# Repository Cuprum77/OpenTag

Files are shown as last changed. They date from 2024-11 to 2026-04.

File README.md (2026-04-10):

# OpenTag

OpenTag is a project for building custom Bluetooth location finding beacons based on existing Apple and Google location finding networks. This repository contains the hardware and firmware for and STM32WB5x/35xx based "Polyglot" tag that can use both Google and Apple finding networks simultaneously. The repository also contains 3D printable enclosures for the tag as well as a docker based web interface for aggregating the results from the different location fetching backends.

## Backends
We did not invent or even do anything novel in terms of reverse engineering the Apple and Google finding networks. Thus, we rely on third party implementations of both to do the heavy lifting needed to make this project feasible, in particular:
- [Macless-Haystack](https://github.com/dchristl/macless-haystack) Used for fetching location data from the Apple finding network.
- [GoogleFindMyTools](https://github.com/leonboe1/GoogleFindMyTools) Used as a base for the Google finding network backend. (Note: A fork with additional features such as key rotation, compound tags and more was created based on GoogleFindMyTools and is used in this project, the fork is available [here](https://github.com/diminDDL/OpenTagBridge)).

## Hardware
The hardware design (located in the [hardware](./hardware) directory) for the Polyglot tag is based on the STM32WB5x/35xx series of microcontrollers and is powered with a single CR2032 battery. When actively advertising payloads it consumes around 3mA, in deep sleep that number drops to 3uA. By default the tag wakes up every 10 seconds for a ~25ms long advertising window and with a single 230mAh CR2032 cell the tag is expected to last for about 2 years and 6 months. The parameters can be adjusted for different use cases and battery life tradeoffs. The following formula can be used to estimate battery lifetime:

$$
I_{\mathrm{avg}}=
I_{\mathrm{active}}\cdot\frac{t_{\mathrm{active}}}{T_{\mathrm{cycle}}}
+
I_{\mathrm{sleep}}\cdot\left(1-\frac{t_{\mathrm{active}}}{T_{\mathrm{cycle}}}\right)
$$

$$
\text{Battery Life (years)} =
\frac{C_{\mathrm{bat}}}{I_{\mathrm{avg}}\cdot 24 \cdot 365}
$$

or equivalently

$$
\text{Battery Life (years)} =
\frac{C_{\mathrm{bat}}}
{\left(
I_{\mathrm{active}}\cdot\frac{t_{\mathrm{active}}}{T_{\mathrm{cycle}}}
+
I_{\mathrm{sleep}}\cdot\left(1-\frac{t_{\mathrm{active}}}{T_{\mathrm{cycle}}}\right)
\right)\cdot 24 \cdot 365}
$$

Where by default the parameters are:

$$
I_{\mathrm{active}} = 3.0\ \text{mA}
$$

$$
I_{\mathrm{sleep}} = 0.003\ \text{mA}
$$

$$
t_{\mathrm{active}} = 24\ \text{ms}
$$

$$
T_{\mathrm{cycle}} = 10\ \text{s}
$$

$$
C_{\mathrm{bat}} = 230\ \text{mAh}
$$

There is also a large capacitor bank on the board, it is optional, however it contains enough energy for a few advertisement bursts which can prevent the tag from resetting in high vibration environments.

The tag uses an integrated single part matching network from ST and a PCB antenna offering quite consistent RF performance without the need for manual tuning. A 4 layer stackup is used for better RF performance, but it could be simplified to 2 layers and a thinner stackup if needed.

The board also includes 2 LEDs, 2 jumpers for debugging and programming and an SWD pad compatible with a Tag-Connect.

## Firmware
See the [software](./software) directory for the firmware source code, build and programming instructions.

## Mechanical
The [3d_models](./3d_models) directory contains the 3D models for the tag itself, and the [enclosures](./enclosures) directory contains 3D models for enclosures.

## Aggregation and Web Interface
*TODO*

# Disclaimer
> [!CAUTION]
> This project is provided for educational and research purposes only. The authors and contributors disclaim liability and do not condone illegal, unauthorized, or unethical use, including unauthorized tracking or invasions of privacy.
> 
> Use of this project is entirely at your own risk. Interacting with Google or Apple location networks in undocumented or unsupported ways may violate platform rules or terms of service and may result in account penalties, service restrictions, or other consequences. The authors and contributors disclaim liability for misuse of this repository and for any damages or consequences resulting from its use.

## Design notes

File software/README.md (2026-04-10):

# Software Overview

*TODO*

---

# Firmware Installation

The firmware is written in C/C++ using STM32CubeIDE. You don't need to compile the firmware if you are fine with the default settings:
- 1 key broadcast every 10 seconds
- 360 key re-use cycles (key changes once every hour)

You can modify these [here](STM32WB_BT_TAG/STM32_WPAN/App/app_ble.c#L177-L185).

---

### Wireless Stack Installation

1. **Download STM32CubeProgrammer**:  
   Go [here](https://www.st.com/en/development-tools/stm32cubeprog.html) to download the STM32CubeProgrammer.  

2. **Prepare Your Hardware**:  
   *Short the `BOOT0` jumper to the 3V3 rail (2nd jumper from the top on the right side if viewed with antenna up).* This may be optional depending on the state of the flash.

   Connect your board to a debugger (preferably an ST-LINK), and connect the debugger to your computer.
   BOOT0 (top right) and the pinout of the debug connector (bottom right) is shown below:
   
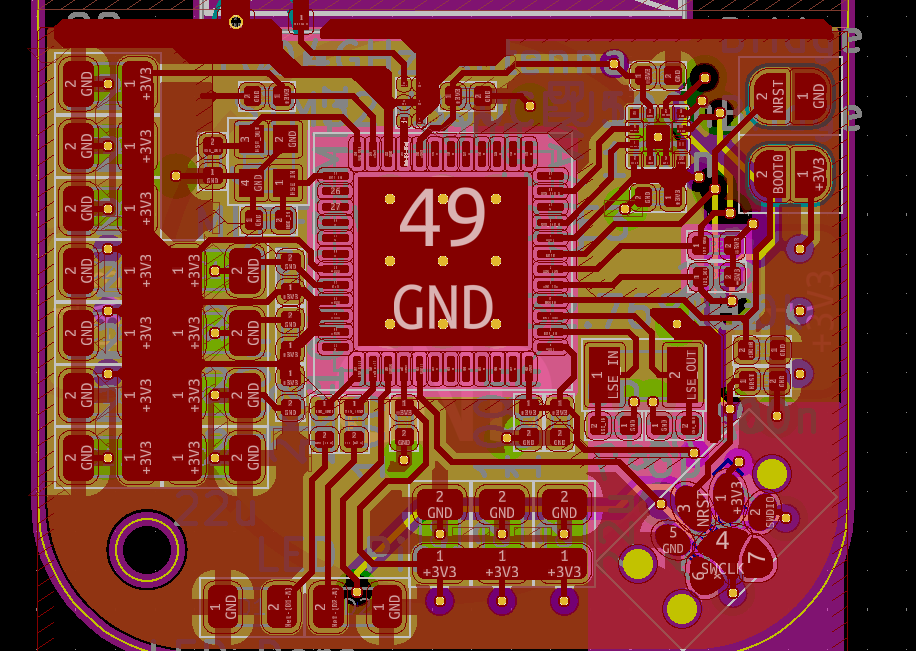
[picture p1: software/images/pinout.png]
Image of the board layout
   

   You only need 3V3, GND, SWDIO, and SWCLK from the debug connector. 

4. **Install the Wireless Stack and Firmware Update Service**:  
   Visit [STM32WB_Copro_Wireless_Binaries](https://github.com/STMicroelectronics/STM32CubeWB/tree/master/Projects/STM32WB_Copro_Wireless_Binaries) and download 3 files:
   - `stm32wb3x_FUS_fw.bin`
   - `stm32wb3x_BLE_Stack_full_fw.bin`
   - `Release_Notes.html`
   
   Open `Release_Notes.html` in your browser. Here you need to find a table called "FW Upgrade Services Binary", it should include an entry for `stm32wb3x_FUS_fw.bin` and the address of where that binary should be programmed to depending on flash size. Use [STM32CubeProgrammer](https://www.st.com/en/development-tools/stm32cubeprog.html) to find what flash size you have (shown in bottom right after you connect to the target).

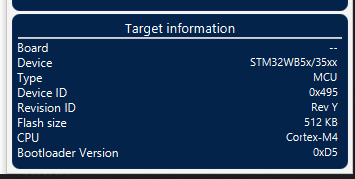
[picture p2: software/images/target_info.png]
Screenshot of STM32CubeProgrammer showing target info
   

   After connecting to the target, open the **"Firmware Upgrade Services"** tab in STM32CubeProgrammer, click **"Start FUS"** under the **"WB Commands"** section, and then **"Read FUS infos"**. This will show you the current FUS version on the MCU. Now select `stm32wb3x_FUS_fw.bin` in the file selector, enter the start address if STM32CubeProgrammer doesn't offer to auto detect the address. Hit **"Firmware Upgrade"** and wait for it to finish, once it's done once again click "Start FUS" and **"Read FUS infos"** and double check if the FUS version matches the one you downloaded.

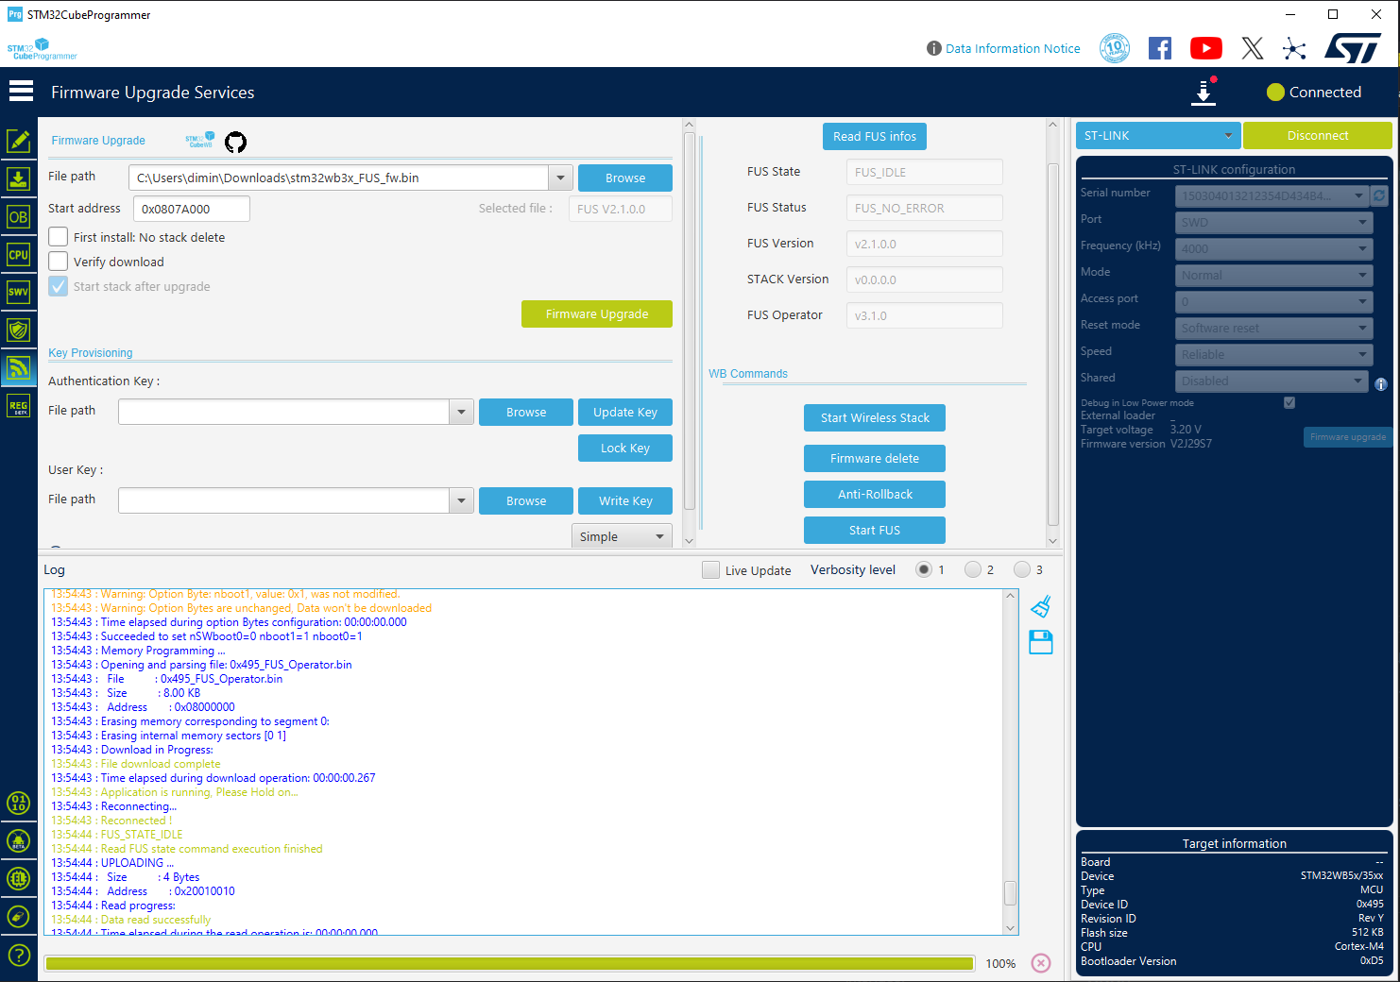
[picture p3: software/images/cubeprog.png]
Screenshot of STM32CubeProgrammer
   

   Now you need to program the BLE stack. Take the `stm32wb3x_BLE_Stack_full_fw.bin` file and find it in `Release_Notes.html` to find the address depending on the flash size. Now select `stm32wb3x_BLE_Stack_full_fw.bin` in the file selector, enter the start address if STM32CubeProgrammer doesn't offer to auto detect the address and hit **"Firmware Upgrade"**. After this is done you should be able to "Read FUS infos" and see a **"STACK Version"** that shows an actual version and is not full of zeroes.

   **⚠️Important⚠️**

   Make absolutely sure you start the wireless stack after you flash it, without pressing that button in STM32CubeProgrammer the BLE will not work at all! The button to do so can be found in the **"Firmware Upgrade Services"** menu under **"WB Commands"**. First disconnect the debugger and make sure to completely power cycle the MCU (short the capacitors for good measure). Next re-connect to the target, and simply click **"Start Wireless Stack"** and wait for confirmation. 

   *If at a later point the tag doesn't advertise anything on Bluetooth then try enabling the wireless stack again, it sometimes resets itself after programming firmware.*

   Follow these instructions if you have any issues:
   - [STM32WB BLE Hardware Setup](https://wiki.st.com/stm32mcu/wiki/Connectivity:STM32WB_BLE_Hardware_Setup)
   - [YouTube Tutorial](https://www.youtube.com/watch?v=-xYoI84zJew&t=568s)  

---

### Firmware Installation

Once the wireless stack is set up, proceed as follows:

1. Open the **"Erasing & Programming"** section in STM32CubeProgrammer.  
2. Select the binary file located [here](STM32WB_BT_TAG/Release/STM32WB_BT_TAG.hex).  
3. Ensure that the **"Skip flash erase before programming"** checkmark is **unchecked**.  
4. Click **Start Programming**.  

Now the MCU has firmware, but keys still need to be installed. Also, now SWD connections won't work if the tag is in deep sleep. So, if the device isn't responding to the debugger power cycle it and try connecting within the first 30 seconds while the LED is blinking.

---

### Key Installation

1. **Generate Keys**:  
   Use the [Macless-Haystack](https://github.com/dchristl/macless-haystack) project to generate Apple keys, specifically the [generate_keys.py](https://github.com/dchristl/macless-haystack/releases/latest/download/generate_keys.py) script, to produce a binary file containing the keys. Once the script produces the files, you need to find the smallest one (`_keyfile` postfix) without an extension and rename it to have a `.bin` at the end. Otherwise STM32CubeProgrammer will not accept it.
   *(Note: Generating multiple keys in the file is left as an exercise for the reader.)*

   Use [OpenTagBridge](https://github.com/diminDDL/OpenTagBridge) to log into Google and register a tracker to get the the Google keys. A `.bin` file will be generated.

2. **Program the Keys**:  
   - Open the **"Erasing & Programming"** section in STM32CubeProgrammer.  
   - Select the generated `.bin` file.  
   - Set the following options:
     - **Unchecked**: "Skip flash erase before programming" (should be blue).
     - **Start Address**: `0x08020000` for Google keys.
     - **Start Address**: `0x08030000` for Apple keys.  
   - Click **Start Programming**.
   - Repeat the above steps for both Apple and Google keys.

The keys are now programmed. Disconnect power and the programmer from the device, ⚠️**DISCHARGE THE CAPACITORS**⚠️, insert a battery, and the device should start broadcasting your keys.

---

## Verifying Tag Functionality

To verify the tag is working:
1. Use [STBLEToolbox](https://www.st.com/en/embedded-software/stbletoolbox.html) on your phone. Place your phone right next to the tag, and put it into scanning mode and wait for several minutes. (You can power cycle the tag to force it to spam some keys at the start).  
2. The tag will report itself as an Apple Device with the following advertisement payload:  
   - **Length**: 26  
   - **Type**: 0xFF  
   - **Value**: 0x...  
3. The app should identify it as an iBeacon.
4. The tag will also advertise itself as a Unknown device with a random MAC address and the following advertisement payload:  
   - **Length**: 25  
   - **Type**: 0x16  
   - **Value**: 0x...

If you see the above advertisements with a high power (-30 to -45dBm) when placed next to your phone then the tag is fully operational and transmitting BLE beacons.

--- 

## Getting Location Data

Please follow the instructions from [Macless-Haystack](https://github.com/dchristl/macless-haystack) on how to setup your apple account and server for receiving location data. In particular `Server setup` and `Frontend setup` should be read and followed thoroughly.

Also, follow the instructions in [OpenTagBridge](https://github.com/diminDDL/OpenTagBridge) on dealing with Google accounts and getting the Google keys.

## Aggregated Web Interface
*TODO*

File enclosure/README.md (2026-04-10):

# Enclosure

The enclosure is designed to snap fit straight from the printer, please print at 0.2mm layer height or below. PETG is recommended for better durability of the snap-fit joints.

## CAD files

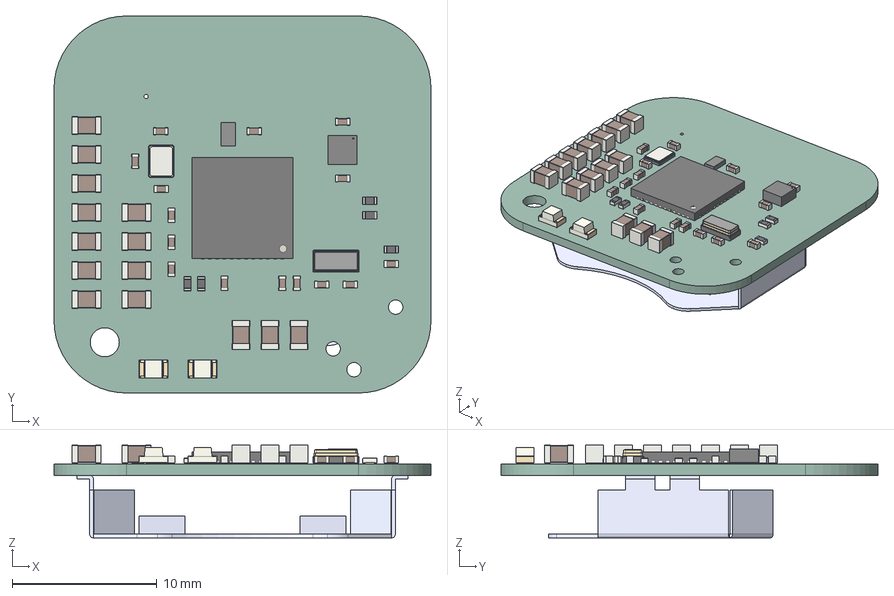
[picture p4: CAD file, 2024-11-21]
3d_models/OpenTag_noTracks.step
26.0 x 26.0 x 6.40 mm
C_0805_2012Metric x 14
C_0402_1005Metric x 15
Crystal_SMD_TXC_7M-4Pin_3.2x2.5mm_HandSoldering
LED_0805_2012Metric x 2
R_0402_1005Metric x 5
MLPF-WB55-01E3
QFN-48-1EP_7x7mm_Pitch0.5mm
Crystal_SMD_3215-2Pin_3.2x1.5mm
root
OpenTag_PCB

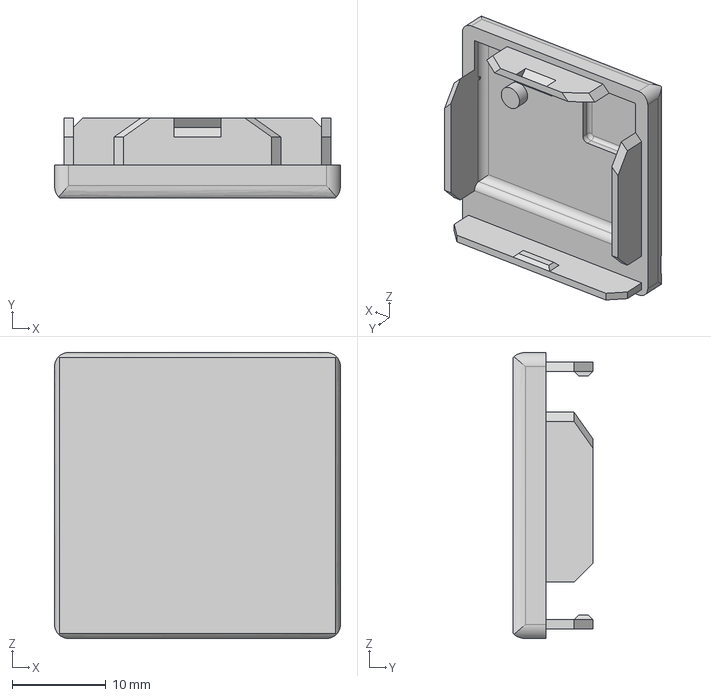
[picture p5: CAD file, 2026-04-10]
enclosure/OpenTagCase_top.step
30.5 x 8.50 x 30.5 mm

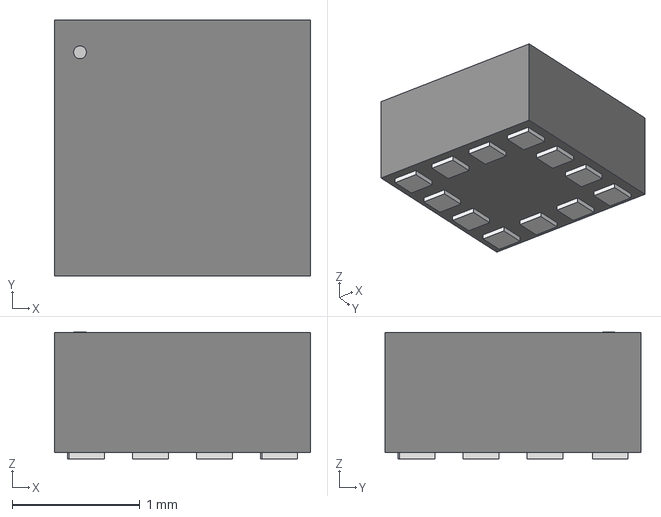
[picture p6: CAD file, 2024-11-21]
hardware/3D/QFN_BMA400_BOS.step
2.01 x 2.01 x 0.993 mm

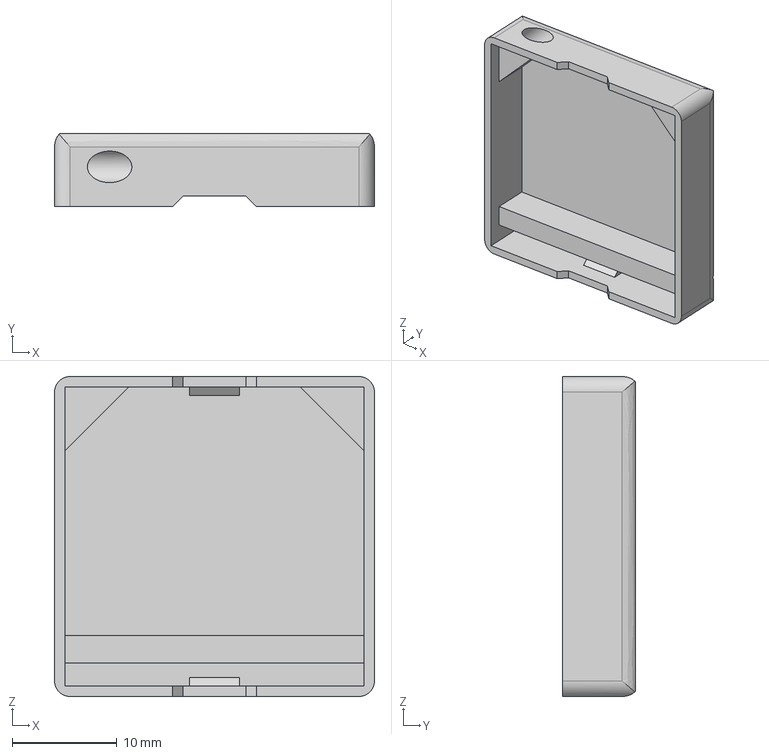
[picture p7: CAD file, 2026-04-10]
enclosure/OpenTagCase_bottom.step
30.5 x 7.00 x 30.5 mm

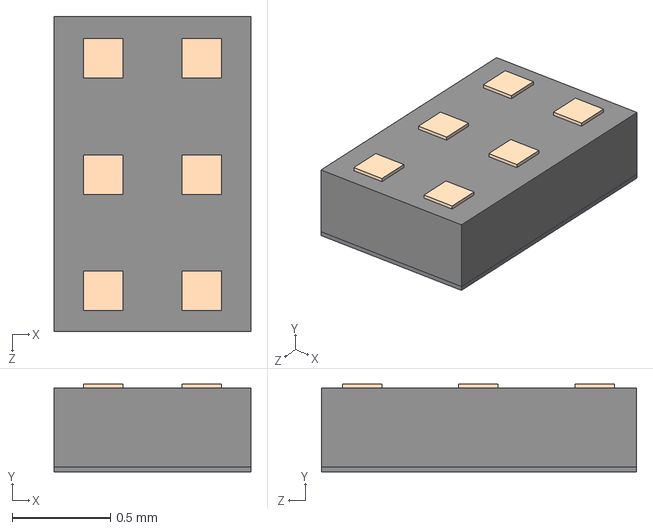
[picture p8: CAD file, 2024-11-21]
hardware/3D/MLPF-WB55-01E3.stp
1.00 x 0.445 x 1.60 mm

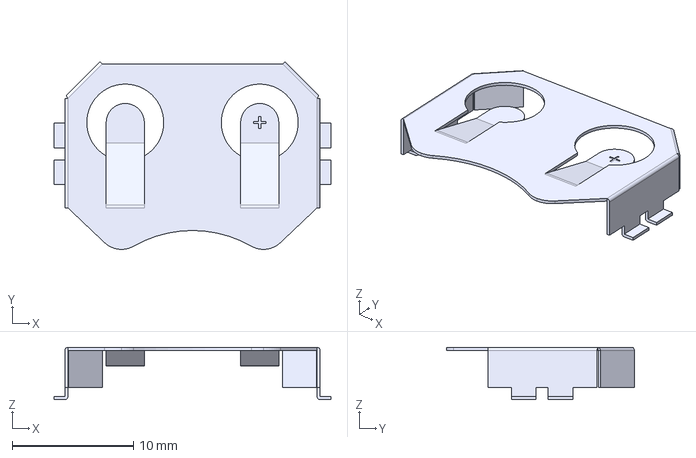
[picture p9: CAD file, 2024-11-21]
hardware/3D/BAT-HLD-001.stp
22.9 x 15.5 x 4.32 mm

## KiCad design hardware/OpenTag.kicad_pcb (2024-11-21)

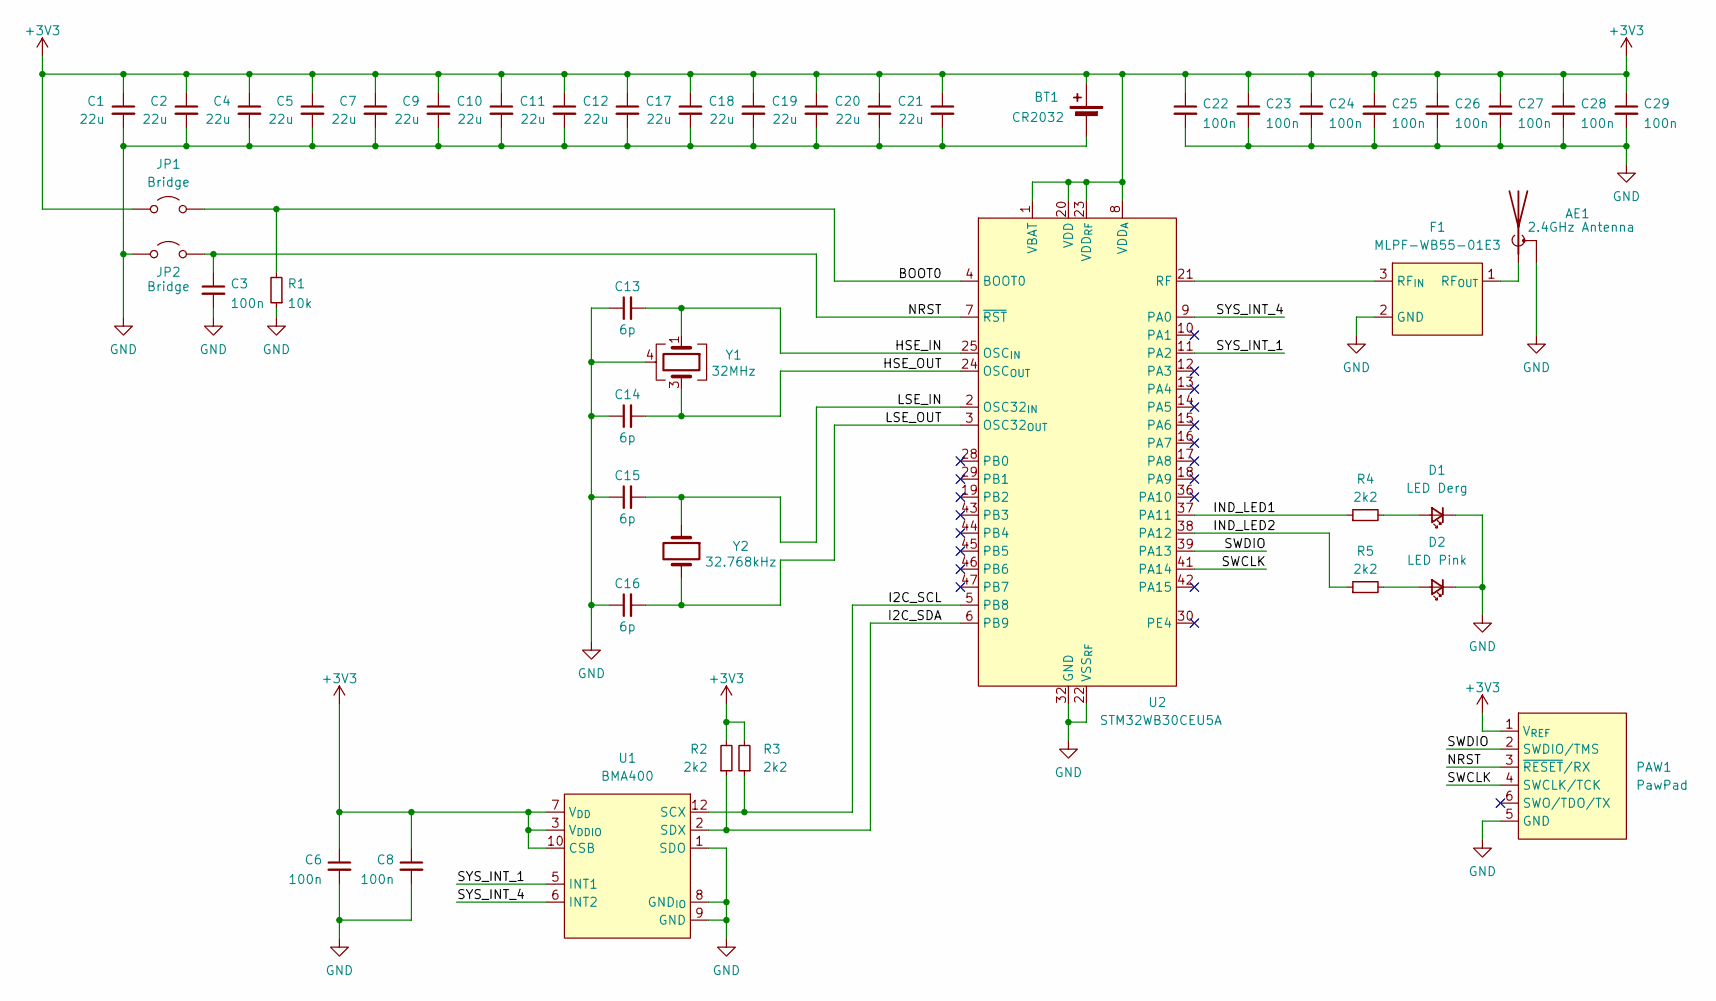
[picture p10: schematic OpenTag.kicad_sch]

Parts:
AE1: 2.4GHz Antenna; Texas_SWRA117D_2.4GHz_Right
BT1: CR2032; BAT-HLD-001
C1, C2, C4, C5, C7, C9, C10, C11, C12, C17, C18, C19, C20, C21: 22u; C_0805_2012Metric
C3, C6, C8, C22, C23, C24, C25, C26, C27, C28, C29: 100n; C_0402_1005Metric
C13, C14, C15, C16: 6p; C_0402_1005Metric
D1: LED Derg; LED_0805_2012Metric
D2: LED Pink; LED_0805_2012Metric
F1: MLPF-WB55-01E3; ST-Bumpless-CSP-6
JP1, JP2: Bridge; SolderJumper-2_P1.3mm_Open_RoundedPad1.0x1.5mm
PAW1: PawPad; Paw-Connect_RevB_TC2030-IDC-NL_2x03_P1.27mm_Vertical
R1: 10k; R_0402_1005Metric
R2, R3, R4, R5: 2k2; R_0402_1005Metric
U1: BMA400; LGA-12
U2: STM32WB30CEU5A; QFN-48-1EP_7x7mm_P0.5mm_EP5.45x5.45mm
Y1: 32MHz; Crystal_SMD_2016-4Pin_2.0x1.6mm
Y2: 32.768kHz; Crystal_SMD_3215-2Pin_3.2x1.5mm

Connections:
+3V3: BT1.1 (+), C1.1, C2.1, C4.1, C5.1, C6.1, C7.1, C8.1, C9.1, C10.1, C11.1, C12.1, C17.1, C18.1, C19.1, C20.1, C21.1, C22.1, C23.1, C24.1, C25.1, C26.1, C27.1, C28.1, C29.1, JP1.1 (A), PAW1.1 (V_{REF}), R2.2, R3.2, U1.3 (V_{DDIO}), U1.7 (V_{DD}), U1.10 (CSB), U2.1 (VBAT), U2.8 (VDD_{A}), U2.20 (VDD), U2.23 (VDD_{RF}), U2.31 (VDD), U2.33 (VDD), U2.34 (VDD), U2.35 (VDD), U2.40 (VDD), U2.48 (VDD)
/BOOT0: JP1.2 (B), R1.2, U2.4 (BOOT0)
/HSE_IN: C13.2, U2.25 (OSC_{IN}), Y1.1
/HSE_OUT: C14.2, U2.24 (OSC_{OUT}), Y1.3
/I2C_SCL: R3.1, U1.12 (SCX), U2.5 (PB8)
/I2C_SDA: R2.1, U1.2 (SDX), U2.6 (PB9)
/IND_LED1: R4.1, U2.37 (PA11)
/IND_LED2: R5.1, U2.38 (PA12)
/LSE_IN: C15.2, U2.2 (OSC32_{IN}), Y2.1
/LSE_OUT: C16.2, U2.3 (OSC32_{OUT}), Y2.2
/NRST: C3.1, JP2.2 (B), PAW1.3 (~RESET/RX), U2.7 (~RST)
/SWCLK: PAW1.4 (SWCLK/TCK), U2.41 (PA14)
/SWDIO: PAW1.2 (SWDIO/TMS), U2.39 (PA13)
/SYS_INT_1: U1.5 (INT1), U2.11 (PA2)
/SYS_INT_4: U1.6 (INT2), U2.9 (PA0)
GND: AE1.2 (Shield), BT1.2 (-), C1.2, C2.2, C3.2, C4.2, C5.2, C6.2, C7.2, C8.2, C9.2, C10.2, C11.2, C12.2, C13.1, C14.1, C15.1, C16.1, C17.2, C18.2, C19.2, C20.2, C21.2, C22.2, C23.2, C24.2, C25.2, C26.2, C27.2, C28.2, C29.2, D1.1 (K), D2.1 (K), F1.2 (GND), F1.4 (GND), F1.5 (GND), F1.6 (GND), JP2.1 (A), PAW1.5 (GND), R1.1, U1.1 (SDO), U1.8 (GND_{IO}), U1.9 (GND), U2.22 (VSS_{RF}), U2.32 (GND), U2.49 (EP), Y1.2, Y1.4
unnamed: AE1.1 (A), F1.1 (RF_{OUT})
unnamed: D1.2 (A), R4.2
unnamed: D2.2 (A), R5.2
unnamed: F1.3 (RF_{IN}), U2.21 (RF)

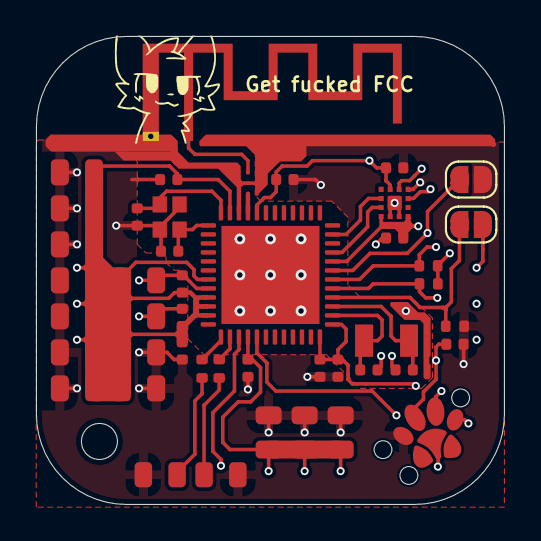
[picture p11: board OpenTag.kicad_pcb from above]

Board: 4 copper layers, 26.0 x 26.0 mm, 46 parts (1 on the bottom side), 20 nets.

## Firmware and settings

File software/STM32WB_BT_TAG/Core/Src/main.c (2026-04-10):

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
/* Includes ------------------------------------------------------------------*/
#include "main.h"

/* USER CODE BEGIN Includes */
#include "stm32_lpm.h"
/* USER CODE END Includes */

CRC_HandleTypeDef hcrc;

IPCC_HandleTypeDef hipcc;

RTC_HandleTypeDef hrtc;

/* USER CODE BEGIN PV */
bool cold_start_flag = true;

/* USER CODE END PV */

void SystemClock_Config(void);
void PeriphCommonClock_Config(void);
static void MX_GPIO_Init(void);
static void MX_IPCC_Init(void);
static void MX_RTC_Init(void);
static void MX_CRC_Init(void);
static void MX_RF_Init(void);
/* USER CODE BEGIN 0 */
union flashdata{
    uint32_t data_word;
    uint8_t data_bytes[4];
}flashmem_data;
/* USER CODE END 0 */

/**
  * @brief  The application entry point.
  * @retval int
  */
int main(void)
{

  /* MCU Configuration--------------------------------------------------------*/

  /* Reset of all peripherals, Initializes the Flash interface and the Systick. */
  HAL_Init();
  /* Config code for STM32_WPAN (HSE Tuning must be done before system clock configuration) */
  MX_APPE_Config();

  /* Configure the system clock */
  SystemClock_Config();

  /* Configure the peripherals common clocks */
  PeriphCommonClock_Config();

  /* IPCC initialisation */
  MX_IPCC_Init();

  /* Initialize all configured peripherals */
  MX_GPIO_Init();
  MX_RTC_Init();
  MX_CRC_Init();
  MX_RF_Init();
  /* USER CODE BEGIN 2 */
  cold_start_flag = true; // Set this first start flag to have the TAG remain not asleep for a little bit
	// the configurable (30 seconds by default) window is needed to allow you to attach a debugger to the MCU
	// before it goes to sleep, as well as potentially in the future allow some BT commands for configuration
  /* USER CODE END 2 */

  /* Init code for STM32_WPAN */
  MX_APPE_Init();

  /* Infinite loop */
  /* USER CODE BEGIN WHILE */
  while (1)
  {
    /* USER CODE END WHILE */
    MX_APPE_Process();

    /* USER CODE BEGIN 3 */
    // Everything is in app_ble.c in Send_Out_Adv(void) and some other user code segments
  }
  /* USER CODE END 3 */
}

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


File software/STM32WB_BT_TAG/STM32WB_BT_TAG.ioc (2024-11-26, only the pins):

Mcu.UserName=STM32WB30CEUxA
PA11.GPIO_Label=LED_PIN
PA11.Signal=GPIO_Output
PA13.Signal=SYS_JTMS-SWDIO
PA14.Signal=SYS_JTCK-SWCLK
PC14-OSC32_IN.Signal=RCC_OSC32_IN
PC15-OSC32_OUT.Signal=RCC_OSC32_OUT

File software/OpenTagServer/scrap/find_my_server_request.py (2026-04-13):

import json
import base64
import hashlib
import requests
import argparse
import struct
from datetime import datetime, timedelta
from cryptography.hazmat.primitives.asymmetric import ec
from cryptography.hazmat.primitives import serialization
from Crypto.Cipher import AES

def get_hashed_advertisement_key(private_key_b64):
    """
    Derives the hashed advertisement key from a base64 encoded private key.
    """
    private_key_bytes = base64.b64decode(private_key_b64)
    private_key_int = int.from_bytes(private_key_bytes, 'big')
    
    private_key = ec.derive_private_key(private_key_int, ec.SECP224R1())
    public_key = private_key.public_key()
    
    public_key_x = public_key.public_numbers().x.to_bytes(28, 'big')
    
    hashed_ad_key = hashlib.sha256(public_key_x).digest()
    
    return base64.b64encode(hashed_ad_key).decode('utf-8')

def decrypt_report(report, private_key_b64):
    """
    Decrypts a FindMy report.
    """
    try:
        payload = base64.b64decode(report['payload'])
        
        # Extract parts of the payload
        ephemeral_key_bytes = payload[-83:-26]
        enc_data = payload[-26:-16]
        tag = payload[-16:]

        # Decode private key
        private_key_bytes = base64.b64decode(private_key_b64)
        private_key_int = int.from_bytes(private_key_bytes, 'big')
        private_key = ec.derive_private_key(private_key_int, ec.SECP224R1())

        # Decode ephemeral public key
        ephemeral_public_key = ec.EllipticCurvePublicKey.from_encoded_point(ec.SECP224R1(), ephemeral_key_bytes)

        # ECDH
        shared_key_bytes = private_key.exchange(ec.ECDH(), ephemeral_public_key)

        # KDF
        counter = (1).to_bytes(4, 'big')
        kdf_input = shared_key_bytes + counter + ephemeral_key_bytes
        derived_key = hashlib.sha256(kdf_input).digest()

        decryption_key = derived_key[:16]
        iv = derived_key[16:]

        # AES-GCM Decryption
        cipher = AES.new(decryption_key, AES.MODE_GCM, nonce=iv, mac_len=16)
        decrypted_payload = cipher.decrypt_and_verify(enc_data, tag)

        # Decode payload
        latitude = struct.unpack('>I', decrypted_payload[0:4])[0] / 10000000.0
        longitude = struct.unpack('>I', decrypted_payload[4:8])[0] / 10000000.0
        accuracy = decrypted_payload[8]

        # Correct coordinates
        if latitude > 90: latitude -= 0xFFFFFFFF / 10000000.0
        if latitude < -90: latitude += 0xFFFFFFFF / 10000000.0
        if longitude > 180: longitude -= 0xFFFFFFFF / 10000000.0
        if longitude < -180: longitude += 0xFFFFFFFF / 10000000.0

        # Decode timestamp and confidence
        seen_timestamp_s = struct.unpack('>i', payload[0:4])[0]
        timestamp = datetime(2001, 1, 1) + timedelta(seconds=seen_timestamp_s)
        confidence = payload[4]

        return {
            "latitude": latitude,
            "longitude": longitude,
            "accuracy": accuracy,
            "timestamp": timestamp.isoformat(),
            "confidence": confidence
        }

    except Exception as e:
        return {"error": str(e)}


def fetch_reports(hashed_keys_map, url, days=7, user=None, password=None):
    """
    Fetches location reports from the server.
    """
    hashed_keys = list(hashed_keys_map.keys())
    payload = {
        "ids": hashed_keys,
        "days": days
    }
    
    headers = {
        "Content-Type": "application/json"
    }

    auth = None
    if user and password:
        auth = (user, password)

    print(f"Requesting reports for {len(hashed_keys)} keys from {url}...")
    
    try:
        response = requests.post(url, json=payload, headers=headers, auth=auth)
        response.raise_for_status()
        
        results = response.json().get("results", [])
        print(f"Found {len(results)} reports.")
        return results
        
    except requests.exceptions.RequestException as e:
        print(f"Error fetching reports: {e}")
        return None

def main():
    parser = argparse.ArgumentParser(description="Fetch and decrypt FindMy location reports.")
    parser.add_argument("json_file", help="Path to the JSON file with private keys.")
    parser.add_argument("--url", default="http://localhost:6176", help="URL of the FindMy server.")
    parser.add_argument("--days", type=int, default=7, help="Number of days of reports to fetch.")
    parser.add_argument("--user", help="Username for server authentication.")
    parser.add_argument("--password", help="Password for server authentication.")
    
    args = parser.parse_args()
    
    try:
        with open(args.json_file, 'r') as f:
            keys_data = json.load(f)
    except FileNotFoundError:
        print(f"Error: JSON file not found at {args.json_file}")
        return
    except json.JSONDecodeError:
        print(f"Error: Could not decode JSON from {args.json_file}")
        return

    hashed_keys_map = {}
    for item in keys_data:
        keys_to_process = []
        if "privateKey" in item and item["privateKey"]:
            keys_to_process.append(item["privateKey"])
        
        if "additionalKeys" in item and isinstance(item["additionalKeys"], list):
            keys_to_process.extend(item["additionalKeys"])

        for key in keys_to_process:
            try:
                hashed_key = get_hashed_advertisement_key(key)
                hashed_keys_map[hashed_key] = key
            except Exception as e:
                print(f"Could not process a key for item '{item.get('name', 'Unnamed')}': {e}")

    if not hashed_keys_map:
        print("No valid private keys found in the JSON file.")
        return
        
    reports = fetch_reports(hashed_keys_map, args.url, args.days, args.user, args.password)
    
    if reports:
        print("\n--- Reports ---")
        for report in reports:
            private_key_b64 = hashed_keys_map.get(report['id'])
            if private_key_b64:
                decrypted_data = decrypt_report(report, private_key_b64)
                report['decrypted'] = decrypted_data
            print(json.dumps(report, indent=2))
        print("---------------")

if __name__ == "__main__":
    main()

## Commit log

2024-11-26 added STM32CUBE project
2026-04-10 updated tag to support both apple and google updated docs
    [OpenTagCase_bottom.step, OpenTagCase_top.step]
2026-06-28 Added a tab for creating a "device" out of individual "tags"

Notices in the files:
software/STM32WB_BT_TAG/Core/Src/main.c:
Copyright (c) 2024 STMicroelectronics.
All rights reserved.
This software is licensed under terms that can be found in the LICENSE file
